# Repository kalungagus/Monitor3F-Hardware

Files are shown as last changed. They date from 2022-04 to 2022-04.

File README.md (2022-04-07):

# Monitor3F-Hardware
O projeto atual está destinado ao monitoramento de potência trifásica de uma máquina. Ele foi desenvolvido para levantar as curvas de potência de tornos e fresadoras. Para isto, emprega-se divisores de tensão que estarão ligados a cada fase da máquina através de transformadores. Depois há um divisor de tensão para reduzir a tensão para níveis aceitos por um ESP32 e finalmente adiciona-se uma componente DC de 3.5V e isola-se esta tensão resultante do ESP32 através de um buffer.
O mesmo acontece com o monitoramento de corrente, que é feito através de um transformador de corrente ligado a um resistor. O sinal de corrente também é adicionado a uma componente DC de 3.5V e isolado do ESP32 por um buffer.

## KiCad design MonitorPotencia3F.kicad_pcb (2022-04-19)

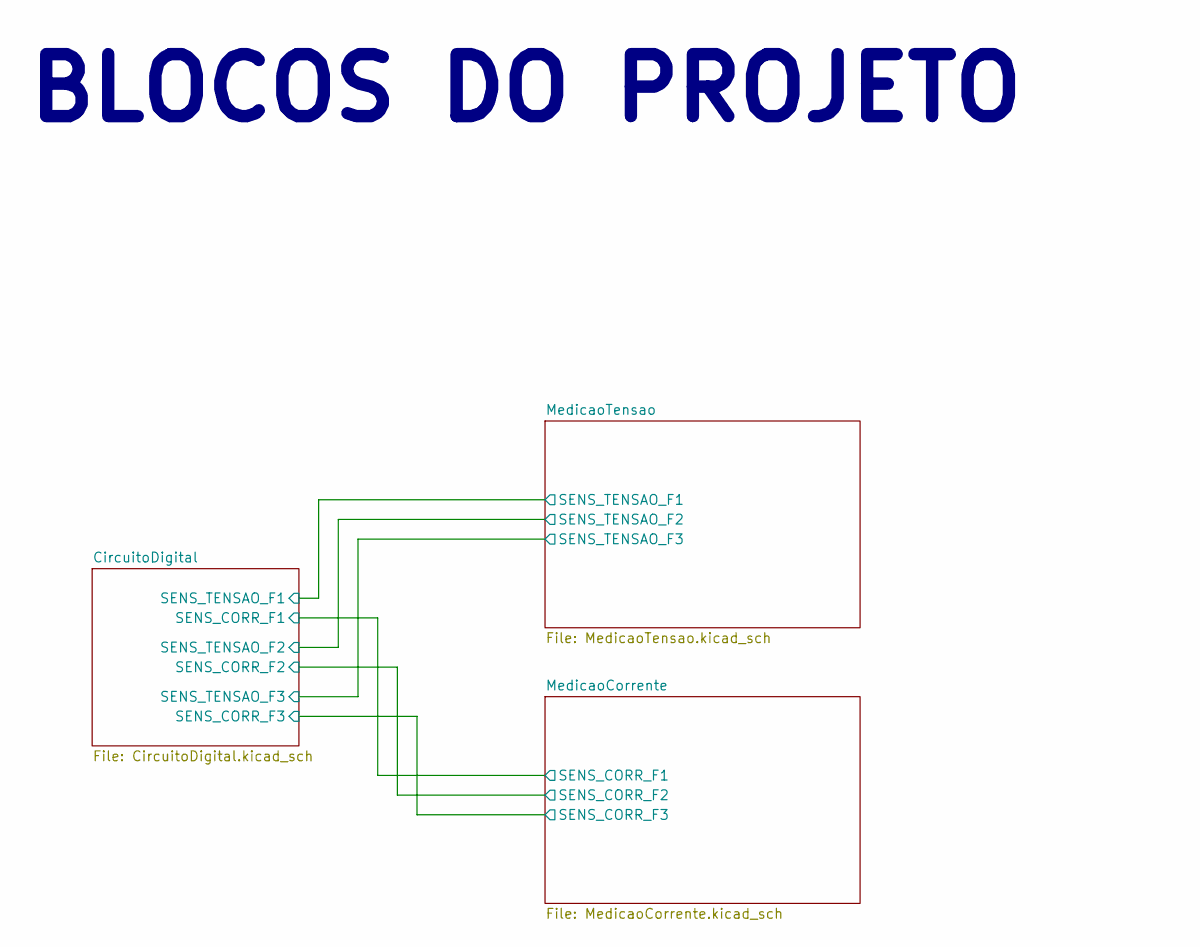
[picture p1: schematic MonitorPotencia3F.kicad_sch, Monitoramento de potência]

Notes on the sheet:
BLOCOS DO PROJETO

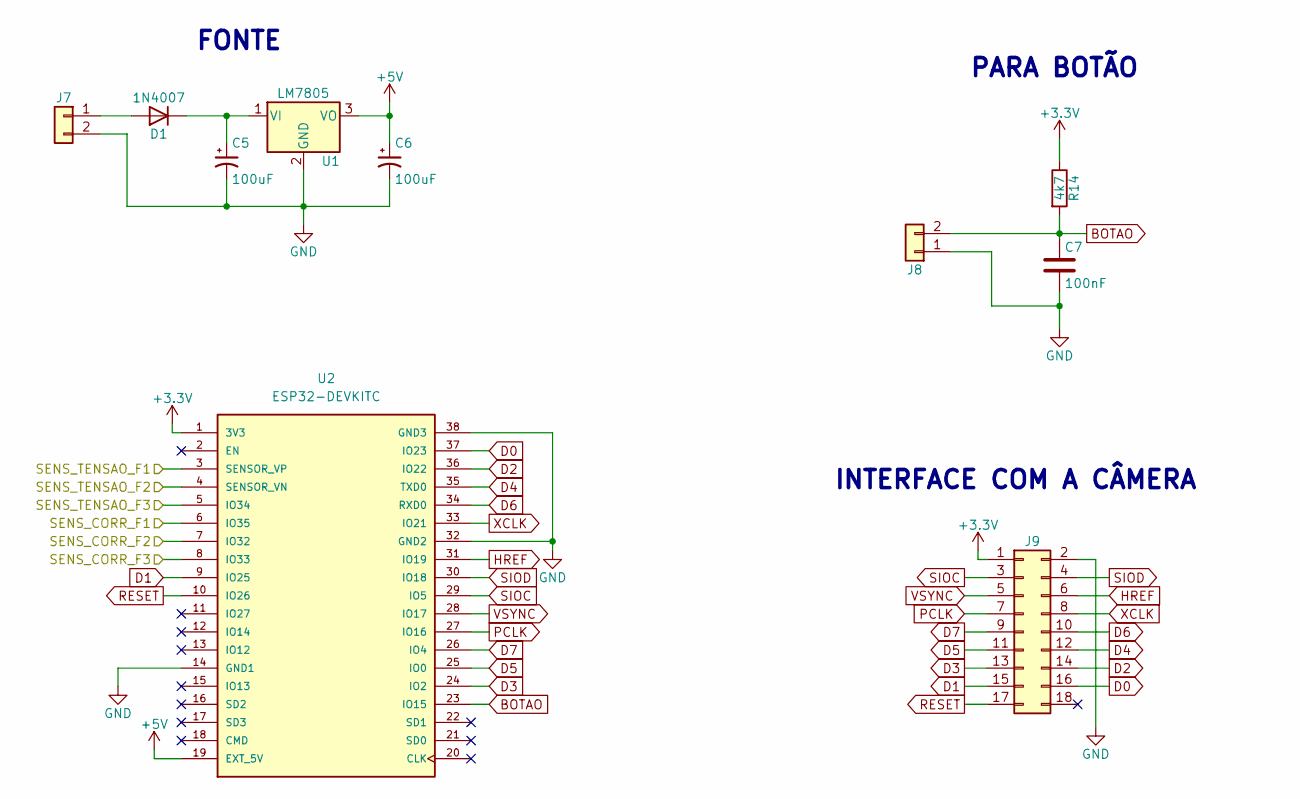
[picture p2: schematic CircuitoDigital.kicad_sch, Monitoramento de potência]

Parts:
C5, C6: 100uF; CP_Radial_D6.3mm_P2.50mm
C7: 100nF; C_Rect_L7.0mm_W2.0mm_P5.00mm
D1: 1N4007; D_DO-41_SOD81_P10.16mm_Horizontal
J7, J8: Conn_01x02; TerminalBlock_bornier-2_P5.08mm
J9: Conn_02x09_Odd_Even; PinHeader_2x09_P2.54mm_Vertical
R14: 4k7; R_Axial_DIN0207_L6.3mm_D2.5mm_P10.16mm_Horizontal
U1: LM7805; TO-220-3_Vertical
U2: ESP32-DEVKITC; MODULE_ESP32-DEVKITC; PARTREV N/A

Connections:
+3V3: J9.1, R14.1, U2.1 (3V3); also elsewhere on the board
+5V: C6.1, U1.3 (VO), U2.19 (EXT_5V); also elsewhere on the board
/CircuitoDigital/SENS_CORR_F1: U2.6 (IO35); also elsewhere on the board
/CircuitoDigital/SENS_CORR_F2: U2.7 (IO32); also elsewhere on the board
/CircuitoDigital/SENS_CORR_F3: U2.8 (IO33); also elsewhere on the board
/CircuitoDigital/SENS_TENSAO_F1: U2.3 (SENSOR_VP); also elsewhere on the board
/CircuitoDigital/SENS_TENSAO_F2: U2.4 (SENSOR_VN); also elsewhere on the board
/CircuitoDigital/SENS_TENSAO_F3: U2.5 (IO34); also elsewhere on the board
BOTAO: C7.1, J8.2, R14.2, U2.23 (IO15)
D0: J9.16, U2.37 (IO23)
D1: J9.15, U2.9 (IO25)
D2: J9.14, U2.36 (IO22)
D3: J9.13, U2.24 (IO2)
D4: J9.12, U2.35 (TXD0)
D5: J9.11, U2.25 (IO0)
D6: J9.10, U2.34 (RXD0)
D7: J9.9, U2.26 (IO4)
GND: C5.2, C6.2, C7.2, J7.2, J8.1, J9.2, U1.2 (GND), U2.14 (GND1), U2.32 (GND2), U2.38 (GND3); also elsewhere on the board
HREF: J9.6, U2.31 (IO19)
unnamed: C5.1, D1.1 (K), U1.1 (VI)
unnamed: D1.2 (A), J7.1
PCLK: J9.7, U2.27 (IO16)
RESET: J9.17, U2.10 (IO26)
SIOC: J9.3, U2.29 (IO5)
SIOD: J9.4, U2.30 (IO18)
VSYNC: J9.5, U2.28 (IO17)
XCLK: J9.8, U2.33 (IO21)

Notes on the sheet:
INTERFACE COM A CÂMERA
PARA BOTÃO
FONTE

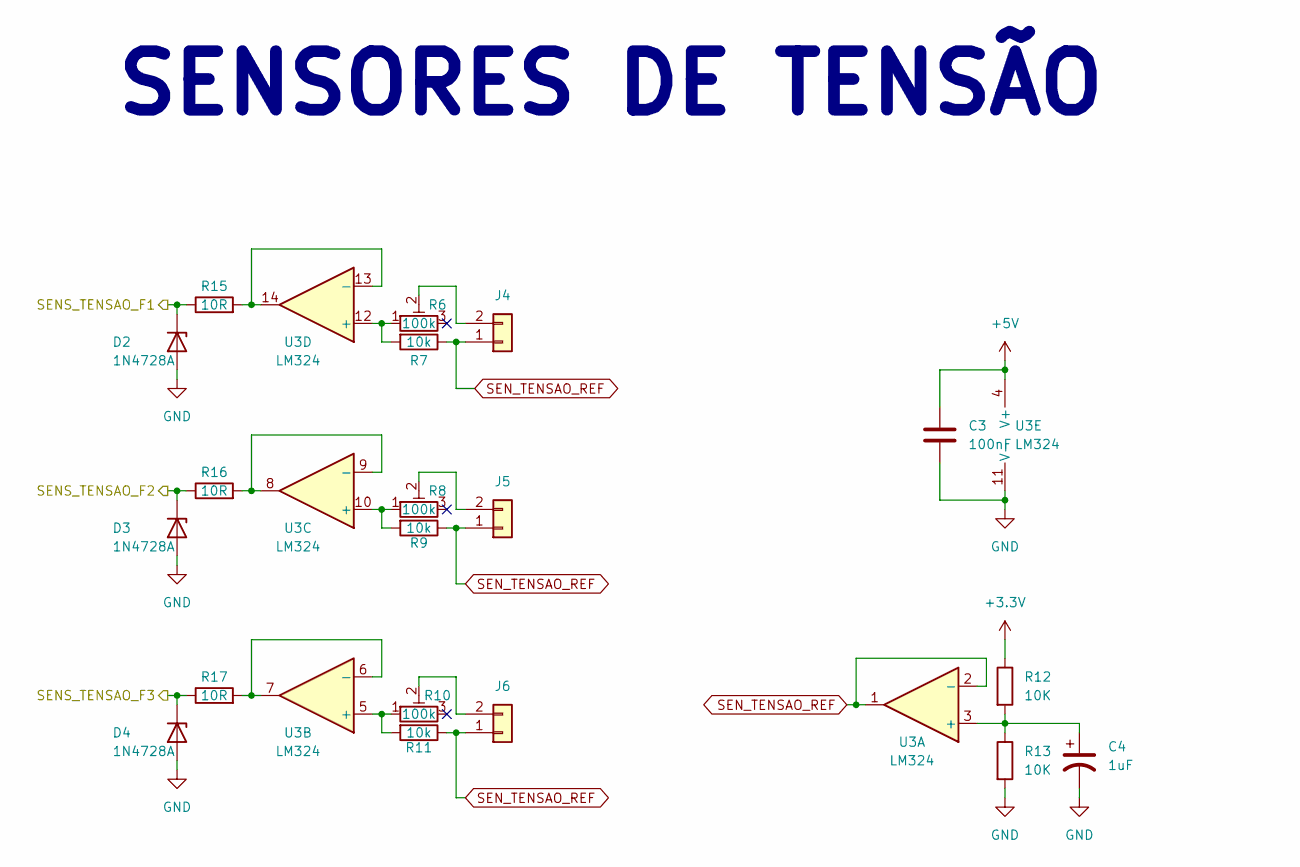
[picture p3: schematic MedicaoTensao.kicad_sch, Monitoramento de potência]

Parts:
C3: 100nF; C_Rect_L7.0mm_W2.0mm_P5.00mm
C4: 1uF; CP_Radial_D6.3mm_P2.50mm
D2, D3, D4: 1N4728A; D_DO-41_SOD81_P10.16mm_Horizontal
J4, J5, J6: Conn_01x02; TerminalBlock_bornier-2_P5.08mm
R6, R8, R10: 100k; Potentiometer_Bourns_3296W_Vertical
R7, R9, R11: 10k; R_Axial_DIN0207_L6.3mm_D2.5mm_P10.16mm_Horizontal
R12, R13: 10K; R_Axial_DIN0207_L6.3mm_D2.5mm_P2.54mm_Vertical
R15, R16, R17: 10R; R_Axial_DIN0207_L6.3mm_D2.5mm_P2.54mm_Vertical
U3: LM324; DIP-14_W7.62mm

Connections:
+3V3: R12.1; also elsewhere on the board
+5V: C3.1, U3.4 (V+); also elsewhere on the board
/CircuitoDigital/SENS_TENSAO_F1: D2.1 (K), R15.1; also elsewhere on the board
/CircuitoDigital/SENS_TENSAO_F2: D3.1 (K), R16.1; also elsewhere on the board
/CircuitoDigital/SENS_TENSAO_F3: D4.1 (K), R17.1; also elsewhere on the board
GND: C3.2, C4.2, D2.2 (A), D3.2 (A), D4.2 (A), R13.2, U3.11 (V-); also elsewhere on the board
unnamed: C4.1, R12.2, R13.1, U3.3 (+)
unnamed: J4.2, R6.2
unnamed: J5.2, R8.2
unnamed: J6.2, R10.2
unnamed: R6.1, R7.2, U3.12 (+)
unnamed: R8.1, R9.2, U3.10 (+)
unnamed: R10.1, R11.2, U3.5 (+)
unnamed: R15.2, U3.13 (-), U3.14
unnamed: R16.2, U3.8, U3.9 (-)
unnamed: R17.2, U3.6 (-), U3.7
SEN_TENSAO_REF: J4.1, J5.1, J6.1, R7.1, R9.1, R11.1, U3.1, U3.2 (-)

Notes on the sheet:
SENSORES DE TENSÃO

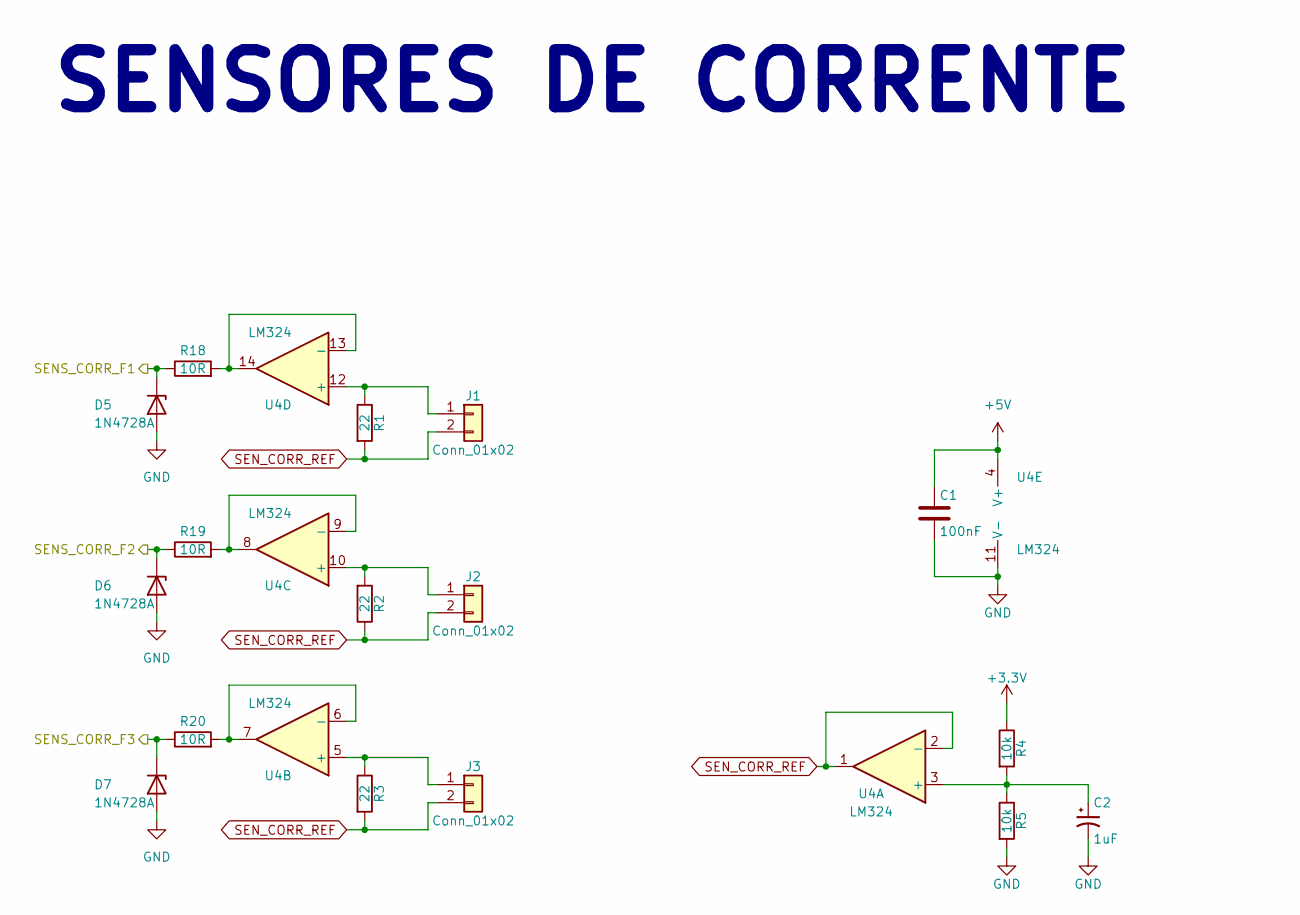
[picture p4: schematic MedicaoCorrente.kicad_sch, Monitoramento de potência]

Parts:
C1: 100nF; C_Rect_L7.0mm_W2.0mm_P5.00mm
C2: 1uF; CP_Radial_D6.3mm_P2.50mm
D5, D6, D7: 1N4728A; D_DO-41_SOD81_P10.16mm_Horizontal
J1, J2, J3: Conn_01x02; TerminalBlock_bornier-2_P5.08mm
R1, R2, R3: 22; R_Axial_DIN0207_L6.3mm_D2.5mm_P10.16mm_Horizontal
R4, R5: 10k; R_Axial_DIN0207_L6.3mm_D2.5mm_P10.16mm_Horizontal
R18, R19, R20: 10R; R_Axial_DIN0207_L6.3mm_D2.5mm_P2.54mm_Vertical
U4: LM324; DIP-14_W7.62mm

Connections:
+3V3: R4.1; also elsewhere on the board
+5V: C1.1, U4.4 (V+); also elsewhere on the board
/CircuitoDigital/SENS_CORR_F1: D5.1 (K), R18.1; also elsewhere on the board
/CircuitoDigital/SENS_CORR_F2: D6.1 (K), R19.1; also elsewhere on the board
/CircuitoDigital/SENS_CORR_F3: D7.1 (K), R20.1; also elsewhere on the board
GND: C1.2, C2.2, D5.2 (A), D6.2 (A), D7.2 (A), R5.2, U4.11 (V-); also elsewhere on the board
unnamed: C2.1, R4.2, R5.1, U4.3 (+)
unnamed: J1.1, R1.1, U4.12 (+)
unnamed: J2.1, R2.2, U4.10 (+)
unnamed: J3.1, R3.1, U4.5 (+)
unnamed: R18.2, U4.13 (-), U4.14
unnamed: R19.2, U4.8, U4.9 (-)
unnamed: R20.2, U4.6 (-), U4.7
SEN_CORR_REF: J1.2, J2.2, J3.2, R1.2, R2.1, R3.2, U4.1, U4.2 (-)

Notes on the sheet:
SENSORES DE CORRENTE

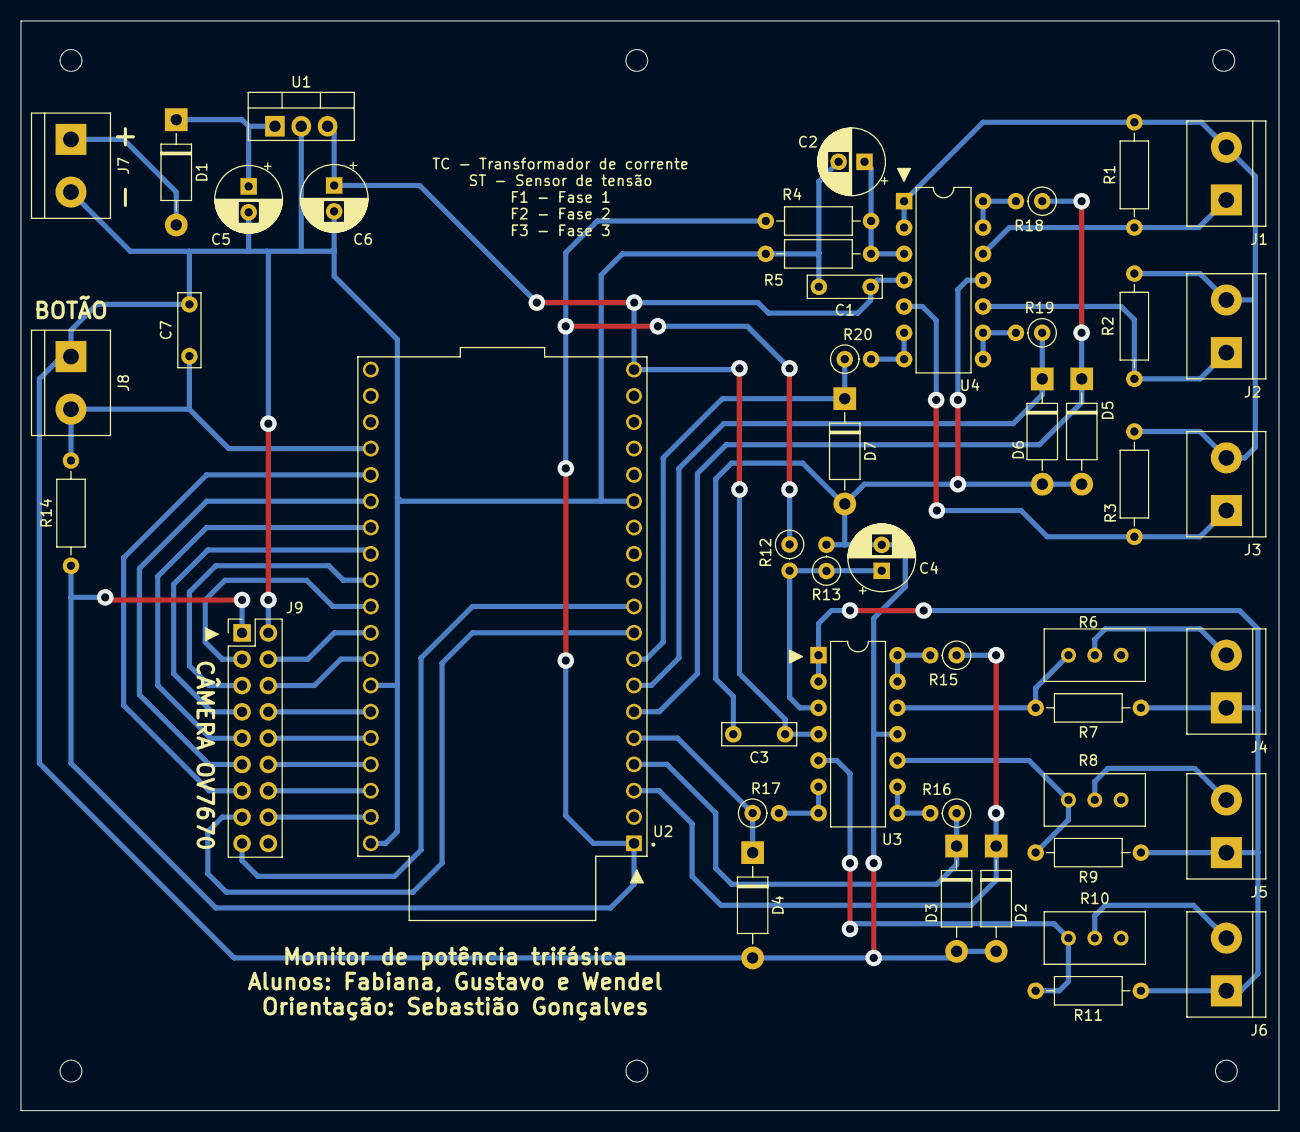
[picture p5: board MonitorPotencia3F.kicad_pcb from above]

Board: 2 copper layers, 121.4 x 105.2 mm, 47 parts (0 on the bottom side), 46 nets.

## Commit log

2022-04-07 Commit inicial do projeto. Esta versão foi produzida para um sensor de tensão externo, com interface para câmera e circuito para sensor de corrente. Ainda existe um botão para iniciar a operação.
    [MonitorPotencia3F.kicad_pcb, MonitorPotencia3F.kicad_sch, MonitorPotencia3F.sch]
2022-04-07 Atualização do projeto com novos sensores de tensão. A referência de tensão para os sensores de corrente também foi atualizada, incluindo um buffer para isolação do divisor de tensão. Os Footprints t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
    [CircuitoDigital.kicad_sch, MedicaoCorrente.kicad_sch, MedicaoTensao.kicad_sch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]
2022-04-08 Adicionado arquivo de Layout
2022-04-08 Adicionado trimpots para a regulagem da entrada dos sensores de tensão. Adicionou-se também um capacitor de desacolpamento para o ESP32.
    [CircuitoDigital.kicad_sch, MedicaoTensao.kicad_sch, MonitorPotencia3F.kicad_sch]
2022-04-11 Adicionado zeners de proteção para a saída dos buffers
    [CircuitoDigital.kicad_sch, MedicaoCorrente.kicad_sch, MedicaoTensao.kicad_sch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]
2022-04-16 As proteções nas saídas dos amplificadores operacionais foram melhoradas e os trimpots foram substituídos por trimpots de 3 pinos, para refletir os que são comprados por aqui.
    [MedicaoCorrente.kicad_sch, MedicaoTensao.kicad_sch, MonitorPotencia3F.kicad_sch]
2022-04-16 Definido todos os footprints para os componentes e feito o DRC
    [CircuitoDigital.kicad_sch, MedicaoCorrente.kicad_sch, MedicaoTensao.kicad_sch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]
2022-04-19 PCB e modelo 3D foram completados. As alterações necessárias foram feitas no esquemático para refletir o projeto desenvolvido na PCB. Teve-se que alterar o modelo do ESP32 para aquele que foi adquiri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
    [CircuitoDigital.kicad_sch, MedicaoCorrente.kicad_sch, MedicaoTensao.kicad_sch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]
